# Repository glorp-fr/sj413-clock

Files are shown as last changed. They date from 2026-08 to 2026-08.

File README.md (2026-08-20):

# Module Horloge / Inclinomètre — Suzuki Samurai SJ413

Remplacement de l'horloge d'origine du tableau de bord d'un Suzuki Samurai
SJ413 (2001) par un module numérique : heure, inclinomètre tangage / roulis
avec silhouettes du véhicule, température extérieure. Basé sur une carte
LilyGO T-Display-S3 (ESP32-S3 + écran IPS 1.9" 170x320), dans un boîtier
imprimé en 3D aux dimensions de la découpe d'origine (63 x 42 mm),
assemblage par clips sans vis.



## Sommaire

- [Fonctionnalités](#fonctionnalités)
- [Matériel](#matériel)
- [Liste des composants (BOM)](#liste-des-composants-bom)
- [Structure du dépôt](#structure-du-dépôt)
- [Câblage](#câblage)
- [Firmware](#firmware)
- [Les écrans](#les-écrans)
- [Impression 3D](#impression-3d)
- [Assemblage](#assemblage)
- [Réglages / dépannage](#réglages--dépannage)
- [Évolutions envisagées](#évolutions-envisagées)
- [Historique des révisions](#historique-des-révisions)

## Fonctionnalités

- **Inclinomètre** : écran coupé en deux verticalement — tangage à gauche
  (Samurai vu de profil, roue de secours à l'arrière), roulis à droite
  (vue arrière, roue de secours sur la porte, pneus sous la carrosserie).
  Les silhouettes pivotent par rapport à un horizon fixe.
- **Alerte à deux niveaux par axe** : ambre à l'approche du seuil, rouge
  avec cadre clignotant en critique. Chaque moitié est indépendante.
- **Horloge** temps réel, conserve l'heure véhicule débranché.
- **Température extérieure** par sonde étanche déportée.
- Navigation à 2 boutons — **ceux déjà intégrés à la carte**, aucun bouton
  supplémentaire à câbler.
- Port USB-C accessible depuis l'extérieur du boîtier.
- Mode simulation intégré : tout le firmware tourne sans aucun capteur.

## Matériel

La carte est une **LilyGO T-Display-S3**. Deux points la caractérisent et
conditionnent tout le reste du projet :

**L'écran utilise un bus parallèle 8 bits, pas du SPI.** C'est contre-intuitif
et beaucoup de tutoriels se trompent. Il ne faut donc pas configurer
`User_Setup.h` à la main avec des broches SPI : un fichier de configuration
tout prêt existe (voir [Firmware](#firmware)).

**Ce bus consomme énormément de broches** : seules 13 GPIO sont sorties sur
le connecteur, contre une vingtaine sur la plupart des cartes ESP32-S3. Le
projet en utilise 5, il reste donc de la marge, mais ça se planifie.

La carte produit elle-même son 3,3 V : on lui fournit du 5 V sur sa broche
dédiée, et elle alimente tous les capteurs en 3,3 V depuis sa broche 3V3.
**Aucun capteur n'est alimenté en 5 V** — les GPIO de l'ESP32-S3 ne sont pas
tolérants au 5 V, et cette règle élimine tout risque d'en envoyer sur une
entrée par accident.

## Liste des composants (BOM)

| Composant | Spécifications | Qté | Rôle |
| :--- | :--- | :---: | :--- |
| Carte microcontrôleur | LilyGO T-Display-S3 (ESP32-S3, écran IPS 1.9" 170x320, ST7789 parallèle 8 bits) | 1 | Cerveau + affichage + boutons |
| Capteur d'inclinaison | MPU-6050 (6 axes, I2C) | 1 | Tangage / roulis |
| Horloge temps réel | Module RTC DS3231 + pile CR2032 | 1 | Garde l'heure hors tension |
| Sonde de température | DS18B20 étanche, câble 1,5–2 m (1-Wire) | 1 | Température extérieure |
| Résistance | 4,7 kΩ | 1 | Tirage de la ligne 1-Wire |
| Alimentation | Convertisseur DC-DC step-down 12V → 5V, 3A | 1 | Adapte le 12V véhicule |
| Protection | Diode 1N4007 + porte-fusible 1A | 1 lot | Protège du réseau 12V |
| Câblage | Fil souple 24 AWG, gaine thermo, câble Qwiic/JST | 1 lot | Connexions |
| Impression 3D | Filament PETG ou ASA noir mat | ~60 g | Façade + boîtier |

Coût estimé (hors imprimante) : **35–50 €**.

Les micro-boutons silicone 8x8 mm figuraient dans les versions précédentes :
ils ne sont plus nécessaires, les deux boutons de la carte (BOOT et KEY)
tombent exactement sur les broches prévues. La façade conserve toutefois
leurs emplacements dans le fichier CAO, à percer ou non selon le choix
d'implantation finale.

## Structure du dépôt

```
.
├── README.md
├── wiring.jpg
├── firmware/
│   ├── samurai_dashboard/          # firmware principal
│   │   └── samurai_dashboard.ino
│   ├── 00_test_hello_world/        # validation matérielle
│   │   └── 00_test_hello_world.ino
│   └── 01_ecran_inclinometre/      # écran inclinomètre seul
│       └── 01_ecran_inclinometre.ino
└── cad/
    ├── 01_facade_samurai.scad
    └── 02_boitier_corps.scad
```

Chaque croquis est dans un dossier à son nom : c'est ce qu'exige l'IDE
Arduino.

Les deux fichiers `.scad` partagent le même repère de coordonnées et les
mêmes variables (`largeur_trou`, `largeur_patte`, `x_patte_trou`) — une
dimension modifiée doit être reportée dans les deux.

## Câblage

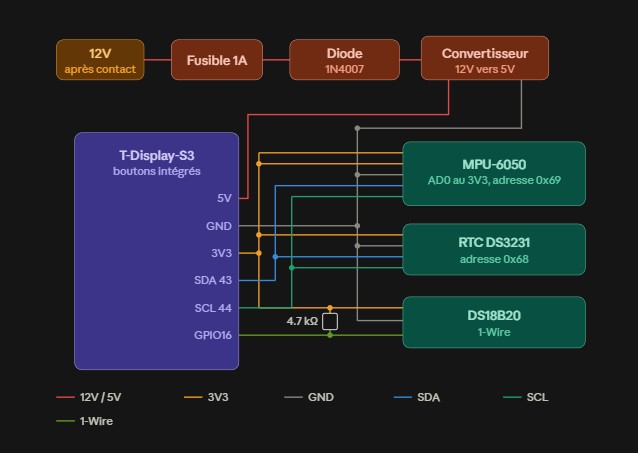
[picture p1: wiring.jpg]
wiring


Convention de lecture : un point noir = connexion réelle ; un croisement de
fils sans point = pas de contact.

### Affectation des broches

| Signal | GPIO | Remarque |
| :--- | :--- | :--- |
| I2C SDA / SCL | 43 / 44 | Connecteur Qwiic / STEMMA QT |
| DS18B20 | 16 | 1-Wire |
| Boutons | 0 (BOOT) / 14 (KEY) | Déjà intégrés à la carte |
| Alimentation périphériques | 15 | **Réservé** — doit rester HIGH |
| Rétroéclairage | 38 | **Réservé** |

Le **connecteur Qwiic** de la carte sort déjà 3V3, GND, SDA et SCL sur une
prise JST 4 points : les capteurs I2C s'y chaînent avec des câbles tout
faits, sans soudure. Dans un boîtier encastré qui vibre, c'est nettement
plus fiable que des fils volants.

Les sources documentaires se contredisent sur les broches I2C par défaut
(43/44 ou 18/17 selon les pages). Vérifiez le marquage de votre carte ;
de toute façon `Wire.begin(SDA, SCL)` permet de les imposer.

### Conflit d'adresses I2C — à ne pas rater

Le MPU-6050 et le DS3231 occupent **tous deux l'adresse 0x68** par défaut.
Il faut relier la broche **AD0 du MPU-6050 au 3V3** pour le basculer en
**0x69**, ce que le firmware attend (`ADRESSE_MPU`). Sans ce cavalier, les
deux capteurs se marchent dessus et aucun ne répond correctement.

### Autres points

- **Masse commune obligatoire** entre convertisseur, carte et capteurs.
  C'est le fil le plus souvent oublié, et la première cause de bus I2C muet.
- **DS18B20** : résistance de 4,7 kΩ entre la ligne de données et le 3V3,
  sauf si votre module l'intègre déjà. Le câble étant long, placez-la côté
  carte, pas côté sonde.
- **Sens de la diode** : bague côté convertisseur, sinon rien ne s'allume.
- **Alimentez sur le +12V après contact**, pas sur le permanent, sinon le
  module tourne en continu et vide la batterie en quelques jours. Le DS3231
  garde l'heure grâce à sa pile.

## Firmware

### Configuration préalable de TFT_eSPI (une seule fois)

Dans le dossier de la bibliothèque `TFT_eSPI`, ouvrir `User_Setup_Select.h`,
commenter la ligne active et décommenter :

```cpp
#include <User_Setups/Setup206_LilyGo_T_Display_S3.h>
```

Ne modifiez pas `User_Setup.h` à la main : cette carte est en parallèle
8 bits, un brochage SPI trouvé sur un blog ne fonctionnera pas. Ce fichier
est **écrasé à chaque mise à jour de la bibliothèque** — si l'écran redevient
noir sans raison, c'est presque toujours ça.

### Réglages Arduino IDE

| Option | Valeur |
| :--- | :--- |
| Carte | ESP32S3 Dev Module |
| USB CDC On Boot | Enabled |
| Flash Size | 16MB (128Mb) |
| Partition Scheme | 16M Flash (3M APP/9.9MB FATFS) |
| PSRAM | **OPI PSRAM** |
| USB Mode | CDC and JTAG |

LilyGO signale que `TFT_eSPI` ne fonctionne pas correctement avec les
versions du paquet **esp32 supérieures à 2.0.14**. Écran noir alors que tout
le reste semble bon : redescendez en 2.0.14.

### Bibliothèques

`TFT_eSPI` (Bodmer), `Adafruit MPU6050` + `Adafruit Unified Sensor`,
`RTClib` (Adafruit), `OneWire` + `DallasTemperature` (Miles Burton).

### Mode simulation

En tête de `samurai_dashboard.ino` :

```cpp
#define SIMULATION 1
```

À `1`, tout tourne **sans aucun capteur branché** : angles sinusoïdaux
balayant les trois niveaux d'alerte, heure interne, température factice.
À `0`, les capteurs réels sont utilisés. Les deux chemins de compilation
sont indépendants — en simulation, aucune bibliothèque de capteur n'est
même incluse.

### Ordre de mise en route conseillé

1. `00_test_hello_world` — valide écran, boutons et liaison série. Rien de
   branché, juste l'USB-C.
2. `01_ecran_inclinometre` — l'écran inclinomètre seul, en simulation.
3. `samurai_dashboard` en `SIMULATION 1` — l'ensemble des modes.
4. Câbler les capteurs, passer en `SIMULATION 0`.

### Premier réglage de l'heure

Décommenter **une seule fois** la ligne `rtc.adjust(...)` dans `setup()`,
téléverser, puis la recommenter et téléverser à nouveau — sinon l'heure
repart à la date de compilation à chaque redémarrage.

### Commandes

| Action | Effet |
| :--- | :--- |
| KEY, appui court | Mode suivant (inclinomètre → horloge → veille) |
| BOOT, appui long | Calibrage du zéro de l'inclinomètre |

Le calibrage se fait **véhicule à plat, moteur arrêté** : il moyenne 16
lectures et mémorise l'écart comme nouvelle référence.

## Les écrans

### Inclinomètre

L'écran est coupé en deux verticalement. À gauche le tangage avec le Samurai
vu de profil ; à droite le roulis avec la vue arrière. Une ligne d'horizon
en pointillés reste fixe : c'est le véhicule qui bascule par rapport à elle,
comme sur un horizon artificiel.

Les silhouettes sont tracées en trigonométrie, pas en bitmap : elles
pivotent réellement, sans stocker d'images.

**Saturation graphique :** la silhouette de profil est longue, donc au-delà
de ~34° ses extrémités viendraient chevaucher le titre et la valeur. Le
dessin est donc saturé à cette limite, **mais la valeur numérique affichée
reste toujours l'angle réel**. C'est le comportement des vrais indicateurs :
le graphique bute, le chiffre continue.

### Seuils d'alerte

| Niveau | Silhouette | Titre + valeur | Cadre |
| :--- | :--- | :--- | :--- |
| Normal | vert | blanc | — |
| Approche | ambre | ambre | — |
| Critique | rouge | rouge | rouge clignotant |

Valeurs par défaut : roulis 22° / 30°, tangage 27° / 35°. Le roulis est plus
bas car sur un Samurai (empattement court, voie étroite, centre de gravité
haut) c'est le basculement latéral le vrai danger ; en montée on perd
l'adhérence ou on recule bien avant de basculer.

> **Ces valeurs sont un point de départ volontairement conservateur, pas
> une limite constructeur.** L'angle réel de bascule dépend des pneus, d'un
> éventuel rehaussement, du chargement et surtout d'une galerie de toit — un
> Samurai réhaussé et chargé sur le toit part nettement plus tôt. Et un angle
> qui se tient à l'arrêt ne se tient pas en dynamique : une bosse, un
> freinage, un passager qui se déplace suffisent. Cet écran est une aide à la
> lecture du terrain, **jamais une autorisation d'aller jusqu'au seuil**. Si
> vous ajustez ces constantes, faites-le vers le bas.

### Horloge

Heure en grands chiffres, secondes, date et température extérieure. Dessinée
directement sur l'écran sans sprite : le contenu ne change qu'une fois par
seconde, et cela économise les 108 Ko qu'occuperait un sprite plein écran.

## Impression 3D

- Matière : **PETG ou ASA** noir mat. Le PLA se déforme l'été derrière un
  pare-brise (>60 °C dans l'habitacle).
- Hauteur de couche 0,16–0,20 mm, remplissage 20–30 %.
- Façade : face visible contre le plateau, sans support.
- Boîtier : à plat, ouverture vers le haut ; supports légers sous la découpe
  USB-C selon le trancheur.

Les deux fichiers ont été rendus avec OpenSCAD et vérifiés en maillage
2-manifold valide. L'alignement pattes / encoches a été contrôlé
numériquement sur les trois axes.

## Assemblage

1. Relier AD0 du MPU-6050 au 3V3 (adresse 0x69), puis chaîner MPU-6050 et
   DS3231 sur le connecteur Qwiic.
2. Câbler la sonde DS18B20 sur GPIO16 avec sa résistance de tirage.
3. Glisser l'électronique dans le boîtier par l'avant : le PCB bute contre
   l'étagère interne (5 mm), juste derrière la fenêtre de l'écran.
4. Passer le câble 12V/GND par l'ouverture arrière, brancher le
   convertisseur avec diode et fusible en amont.
5. Clipser la façade : les deux pattes s'enfoncent par friction dans les
   encoches. Appuyer fermement et de façon répartie sur toute la largeur,
   pas sur un coin.
6. Insérer dans la découpe du tableau de bord — le débord de 2,5 mm masque
   les bords et les fentes des encoches.
7. Téléverser, régler l'heure du RTC, calibrer le zéro véhicule à plat.

## Réglages / dépannage

| Symptôme | Cause probable |
| :--- | :--- |
| Écran noir | `Setup206` non sélectionné dans `User_Setup_Select.h`, ou paquet esp32 > 2.0.14 |
| Écran noir hors USB | GPIO15 non mis à HIGH |
| Téléversement impossible | Maintenir BOOT, appuyer sur RST, relâcher RST puis BOOT |
| Capteurs I2C muets | AD0 du MPU non relié au 3V3 (conflit 0x68), ou masse non commune |
| Température à `--` | Sonde absente ou résistance de tirage manquante |
| Heure fausse au démarrage | Pile CR2032 vide, ou `rtc.adjust(...)` jamais exécuté |
| Silhouette penchée à l'envers | Inverser `SENS_TANGAGE` ou `SENS_ROULIS` (1 ↔ -1) |
| Clip trop lâche ou trop dur | Ajuster `epaisseur_patte` par pas de 0,1 mm, réimprimer la façade seule |

## Évolutions envisagées

**Boussole.** Le MPU-6050 est un 6 axes, il n'a pas de magnétomètre : il
faut un module supplémentaire (QMC5883L « GY-271 », ~2 €, adresse 0x0D). La
difficulté n'est pas le module mais l'environnement : encastré dans un
tableau de bord en acier, à côté de l'écran et du WiFi, il exige une
calibration hard-iron/soft-iron **faite dans le véhicule, module en place**,
à refaire si quoi que ce soit bouge. Il faut aussi le compenser en
inclinaison — l'accéléromètre du MPU-6050 est déjà là pour ça.

**GPS.** Un ATGM336H (~5 €) ou un NEO-M8N (~12 €) sur UART donne le cap réel
et la vitesse. Le cap GPS n'existe qu'**en mouvement** (au-delà de ~5 km/h),
le magnétomètre est le plus perturbé en roulant : les deux se complètent,
avec un basculement automatique selon la vitesse. Prévoir impérativement un
module à connecteur **IPEX** et une **antenne active déportée** — dans une
cage métallique, une antenne céramique intégrée n'accrochera jamais.

Le GPS pourrait remplacer le DS3231, mais mieux vaut garder le RTC :
l'accrochage prend de 30 s à plusieurs minutes, et jamais en parking
souterrain. Le RTC donne l'heure immédiatement, le GPS le resynchronise.

**Voltmètre batterie**, par pont diviseur sur une entrée ADC.

## Historique des révisions

- **v3** — Correction de deux erreurs importantes des versions précédentes :
  l'écran est en **parallèle 8 bits et non en SPI** (avec le fichier
  `Setup206` à sélectionner, au lieu d'une configuration manuelle vouée à
  l'échec), et le **conflit d'adresse I2C 0x68** entre MPU-6050 et DS3231
  (AD0 au 3V3 → 0x69). Ajout de l'écran inclinomètre avec silhouettes de
  Samurai, alertes à deux niveaux par axe, mode simulation complet, tableau
  d'affectation des broches, suppression des boutons externes au profit de
  ceux de la carte, clarification de l'alimentation en 3,3 V.
- **v2** — Correction d'un maillage STL non-manifold sur la façade,
  correction des 4 premiers mm du boîtier pleins par erreur, réalignement
  vérifié des clips, clip par crochet remplacé par un clip par interférence,
  ré-ajout du RTC et de la sonde de température au BOM, anti-rebond du
  firmware rendu non bloquant.
- **v1** — Version initiale.

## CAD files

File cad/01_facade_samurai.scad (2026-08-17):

// ============================================================
// MODULE HORLOGE / INCLINOMÈTRE SUZUKI SAMURAI SJ413
// Pièce 1/2 : FAÇADE AVANT — 01_facade_samurai.scad
// Carte : ESP32-S3 avec écran IPS 1.9" intégré (170x320, ST7789)
// Assemblage : pattes rectangulaires en interférence (pas de vis)
// ============================================================
// IMPORTANT — repère PARTAGÉ avec 02_boitier_corps.scad :
// (0,0) = coin bas-gauche de la DÉCOUPE DU TABLEAU DE BORD
// (63x42mm), PAS le coin de la façade elle-même. La façade
// déborde donc de -rebord_facade à largeur_trou+rebord_facade.
// Toute position de patte/bouton/écran ci-dessous est exprimée
// en coordonnées "trou", puis translatée de +rebord_facade pour
// entrer dans le repère local du panneau. Cela permet de copier
// telles quelles les mêmes coordonnées "trou" dans le fichier du
// boîtier sans recalcul.
// ============================================================

$fn = 40;

// --- Dimensions de la découpe d'origine du tableau de bord ---
largeur_trou  = 63.0;
hauteur_trou  = 42.0;
rebord_facade = 2.5;               // débord de la collerette autour du trou

L_facade = largeur_trou + (rebord_facade * 2); // 68 mm
H_facade = hauteur_trou + (rebord_facade * 2); // 47 mm
epaisseur_facade = 3.0;

// --- Zone d'affichage utile de l'écran 1.9" (coord. "trou") ---
largeur_ecran     = 42.5;
hauteur_ecran     = 23.0;
x_ecran_trou      = 3.5;                              // marge à gauche
y_ecran_trou      = (hauteur_trou - hauteur_ecran)/2;  // centré verticalement

// --- Boutons poussoirs silicone 8x8x5mm (jeu de perçage 0.2mm) ---
largeur_bouton = 8.2;
hauteur_bouton = 8.2;
x_bouton_trou      = 50.0;
y_bouton_haut_trou = 9.5;
y_bouton_bas_trou  = 24.3;

// --- Pattes d'assemblage en interférence (clips sans vis) ---
// Cohérent avec 02_boitier_corps.scad :
largeur_patte   = 15.0;
epaisseur_patte = 1.9;   // légèrement > l'ouverture de l'encoche -> interférence
longueur_patte  = 4.0;   // reste dans la zone d'étagère avant du boîtier (voir profondeur_ledge)
x_patte_trou    = (largeur_trou - largeur_patte) / 2;   // centré en largeur : 24.0

module rectangle_arrondi(l, h, r) {
    hull() {
        translate([r, r]) circle(r=r);
        translate([l-r, r]) circle(r=r);
        translate([l-r, h-r]) circle(r=r);
        translate([r, h-r]) circle(r=r);
    }
}

// Patte simple avec léger chanfrein d'entrée (reste manifold via hull)
module patte_interference(largeur, epaisseur, longueur) {
    hull() {
        cube([largeur, epaisseur, 0.1]);                    // base, collée à la façade
        translate([0.6, 0, longueur])
            cube([largeur - 1.2, epaisseur, 0.1]);            // bout chanfreiné, guide l'insertion
    }
}

module facade_1_9() {
    difference() {
        union() {
            // Cadre principal de façade
            linear_extrude(height = epaisseur_facade)
                rectangle_arrondi(L_facade, H_facade, 3.0);

            // Patte haute (s'enfonce dans l'encoche haute du boîtier)
            translate([rebord_facade + x_patte_trou, rebord_facade - epaisseur_patte + 0.4, epaisseur_facade])
                patte_interference(largeur_patte, epaisseur_patte, longueur_patte);

            // Patte basse (s'enfonce dans l'encoche basse du boîtier)
            translate([rebord_facade + x_patte_trou, rebord_facade + hauteur_trou - 0.4, epaisseur_facade])
                patte_interference(largeur_patte, epaisseur_patte, longueur_patte);
        }

        // Fenêtre centrale pour l'écran
        translate([rebord_facade + x_ecran_trou, rebord_facade + y_ecran_trou, -1])
            linear_extrude(height = epaisseur_facade + 6)
                rectangle_arrondi(largeur_ecran, hauteur_ecran, 1.5);

        // Bouton 1 (haut) : cycle des modes d'affichage
        translate([rebord_facade + x_bouton_trou, rebord_facade + y_bouton_haut_trou, -1])
            linear_extrude(height = epaisseur_facade + 6)
                rectangle_arrondi(largeur_bouton, hauteur_bouton, 1.0);

        // Bouton 2 (bas) : calibrage / réglage
        translate([rebord_facade + x_bouton_trou, rebord_facade + y_bouton_bas_trou, -1])
            linear_extrude(height = epaisseur_facade + 6)
                rectangle_arrondi(largeur_bouton, hauteur_bouton, 1.0);
    }
}

facade_1_9();

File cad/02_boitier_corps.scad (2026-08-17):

// ============================================================
// MODULE HORLOGE / INCLINOMÈTRE SUZUKI SAMURAI SJ413
// Pièce 2/2 : CORPS DU BOÎTIER ARRIÈRE — 02_boitier_corps.scad
// Carte : ESP32-S3 avec écran IPS 1.9" intégré (170x320, ST7789)
// ============================================================
// IMPORTANT — repère PARTAGÉ avec 01_facade_samurai.scad :
// (0,0) = coin bas-gauche de la DÉCOUPE DU TABLEAU DE BORD.
// Ce fichier est construit directement dans ce repère (pas de
// débord à soustraire). Les positions des encoches ci-dessous
// utilisent les MÊMES variables "x_patte_trou / largeur_patte /
// longueur_patte" que la façade — gardez-les synchronisées si
// vous modifiez l'une ou l'autre pièce.
// ============================================================

$fn = 40;

// --- Dimensions (doivent rester identiques à celles de la façade) ---
largeur_trou       = 63.0;
hauteur_trou       = 42.0;
profondeur_boitier = 45.0;
epaisseur_paroi    = 2.4;

// --- Étagère interne (ledge) qui retient le PCB contre la vitre ---
// Sur les premiers "profondeur_ledge" mm, l'ouverture est réduite de
// epaisseur_ledge en plus de l'épaisseur de paroi normale : le PCB,
// glissé depuis l'avant, bute sur ce rebord et s'arrête net derrière
// la fenêtre de l'écran.
profondeur_ledge = 5.0;
epaisseur_ledge  = 2.0;

// --- Port USB-C (accès arrière, pour prog./alimentation directe) ---
largeur_usb = 12.0;
hauteur_usb = 7.0;

// --- Encoches d'assemblage (DOIVENT matcher la façade) ---
largeur_patte   = 15.0;
epaisseur_patte = 1.9;
longueur_patte  = 4.0;                              // reste dans la zone d'étagère (< profondeur_ledge)
x_patte_trou    = (largeur_trou - largeur_patte)/2;  // 24.0 — centré, identique à la façade
jeu_largeur     = 0.4;                               // jeu latéral autour de la patte

module rectangle_arrondi(l, h, r) {
    hull() {
        translate([r, r]) circle(r=r);
        translate([l-r, r]) circle(r=r);
        translate([l-r, h-r]) circle(r=r);
        translate([r, h-r]) circle(r=r);
    }
}

module boitier_corps() {
    difference() {
        // Corps principal qui s'enfonce dans le tableau de bord
        linear_extrude(height = profondeur_boitier)
            rectangle_arrondi(largeur_trou, hauteur_trou, 3.0);

        // --- Cavité principale (profonde), paroi standard ---
        translate([epaisseur_paroi, epaisseur_paroi, profondeur_ledge])
            linear_extrude(height = profondeur_boitier - profondeur_ledge + 1)
                rectangle_arrondi(
                    largeur_trou - 2*epaisseur_paroi,
                    hauteur_trou - 2*epaisseur_paroi, 1.5);

        // --- Cavité avant (étagère), ouverture réduite pour retenir le PCB ---
        translate([epaisseur_paroi + epaisseur_ledge, epaisseur_paroi + epaisseur_ledge, -1])
            linear_extrude(height = profondeur_ledge + 1)
                rectangle_arrondi(
                    largeur_trou - 2*(epaisseur_paroi + epaisseur_ledge),
                    hauteur_trou - 2*(epaisseur_paroi + epaisseur_ledge), 1.0);

        // Accès port USB-C au dos (centré, aligné sur le connecteur de la carte)
        translate([largeur_trou/2 - largeur_usb/2, 8.0, profondeur_boitier - 5.0])
            cube([largeur_usb, hauteur_usb, 10.0]);

        // Passage des câbles d'alimentation 12V / GND (régulateur -> faisceau)
        translate([largeur_trou/2 - 8.0, hauteur_trou - 14.0, profondeur_boitier - 5.0])
            cube([16.0, 8.0, 10.0]);

        // --- Encoche haute (reçoit la patte haute de la façade) ---
        // Traverse toute l'épaisseur de la paroi (haut) pour un ajustement
        // par friction — la façade déborde du trou et masque cette fente.
        translate([x_patte_trou - jeu_largeur/2, -2, -0.5])
            cube([largeur_patte + jeu_largeur, 3.0, longueur_patte + 1]);

        // --- Encoche basse (reçoit la patte basse de la façade) ---
        translate([x_patte_trou - jeu_largeur/2, hauteur_trou - 1.0, -0.5])
            cube([largeur_patte + jeu_largeur, 3.0, longueur_patte + 1]);

        // --- Fentes de refroidissement pour l'ESP32-S3 ---
        // En dehors de la zone centrale des encoches (x 22 à 41) et de
        // la zone d'étagère avant : positionnées sur les côtés, plus
        // profondes dans le boîtier (z > 12).
        for (i = [0:2]) {
            translate([4 + i*4, hauteur_trou - epaisseur_paroi - 1, 12])
                cube([2.2, epaisseur_paroi + 2, 25]);
            translate([largeur_trou - 16 + i*4, hauteur_trou - epaisseur_paroi - 1, 12])
                cube([2.2, epaisseur_paroi + 2, 25]);
            translate([4 + i*4, -1, 12])
                cube([2.2, epaisseur_paroi + 2, 25]);
            translate([largeur_trou - 16 + i*4, -1, 12])
                cube([2.2, epaisseur_paroi + 2, 25]);
        }
    }
}

boitier_corps();

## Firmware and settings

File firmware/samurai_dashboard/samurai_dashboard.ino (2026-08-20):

/* ============================================================
 * MODULE HORLOGE / INCLINOMÈTRE — SUZUKI SAMURAI SJ413
 * Carte : LilyGO T-Display-S3 (ESP32-S3 + ST7789 170x320,
 *         bus PARALLÈLE 8 bits — surtout pas du SPI)
 * ------------------------------------------------------------
 * Modes (bouton KEY = mode suivant) :
 *   0. Inclinomètre — écran coupé en deux : tangage (profil) et
 *      roulis (vue arrière), silhouettes de Samurai qui pivotent
 *   1. Horloge      — heure, date, température extérieure
 *   2. Veille       — écran noir
 *
 * Bouton BOOT, appui long : calibrage du zéro de l'inclinomètre
 * (à faire véhicule à plat, moteur arrêté).
 * ------------------------------------------------------------
 * MODE SIMULATION
 * Mettre SIMULATION à 1 pour faire tourner l'ensemble SANS aucun
 * capteur branché (angles sinusoïdaux, heure interne, température
 * factice). Mettre 0 quand les capteurs sont câblés.
 * ------------------------------------------------------------
 * PRÉREQUIS TFT_eSPI (une seule fois) :
 *   Dans User_Setup_Select.h : commenter #include <User_Setup.h>
 *   et décommenter
 *   #include <User_Setups/Setup206_LilyGo_T_Display_S3.h>
 *
 * ARDUINO IDE : ESP32S3 Dev Module / PSRAM OPI / Flash 16MB /
 *   Partition 16M Flash (3M APP/9.9MB FATFS) / USB CDC On Boot
 * ============================================================ */

#define SIMULATION 1

#include <Arduino.h>
#include <TFT_eSPI.h>

#if !SIMULATION
  #include <Wire.h>
  #include <Adafruit_MPU6050.h>
  #include <Adafruit_Sensor.h>
  #include <RTClib.h>
  #include <OneWire.h>
  #include <DallasTemperature.h>
#endif

/* ---------------- Broches ---------------- */
#define PIN_POWER_ON   15    // alimentation des périphériques : DOIT être HIGH
#define PIN_BTN_BOOT    0    // bouton intégré gauche
#define PIN_BTN_KEY    14    // bouton intégré droit
#define PIN_ONEWIRE    16    // sonde DS18B20
#define PIN_I2C_SDA    43    // connecteur Qwiic / STEMMA QT
#define PIN_I2C_SCL    44

/* MPU-6050 forcé en 0x69 (broche AD0 reliée au 3V3) : en 0x68 par
 * défaut il entrerait en conflit avec le DS3231, qui occupe la même
 * adresse. Sans ce cavalier, les deux capteurs se marchent dessus. */
#define ADRESSE_MPU  0x69

/* ---------------- Géométrie de l'affichage ---------------- */
#define LARGEUR_ECRAN    320
#define HAUTEUR_ECRAN    170
#define LARGEUR_PANNEAU  (LARGEUR_ECRAN / 2)

const float   ECHELLE     = 0.48f;   // valeurs validées : aux angles extrêmes
const int16_t CY_VEHICULE = 72;      // la silhouette ne mord ni sur le titre
const int16_t Y_HORIZON   = 84;      // ni sur la valeur

/* La silhouette de profil est longue : au-delà de ~34° ses extrémités
 * viendraient chevaucher le texte. On sature l'inclinaison DESSINÉE ;
 * la valeur numérique affichée reste toujours l'angle réel. */
const float ANGLE_DESSIN_MAX = 34.0f;

/* ---------------- Seuils d'alerte ----------------
 * Deux niveaux par axe. Le roulis est plus bas que le tangage : sur un
 * Samurai (empattement court, voie étroite, centre de gravité haut)
 * c'est le basculement latéral le vrai danger — en montée on perd
 * l'adhérence ou on recule bien avant de basculer.
 *
 * ATTENTION : point de départ VOLONTAIREMENT CONSERVATEUR, pas une
 * limite constructeur. L'angle réel de bascule dépend des pneus, d'un
 * rehaussement, du chargement et surtout d'une galerie de toit. Un
 * angle tenu à l'arrêt ne se tient pas en dynamique : une bosse, un
 * freinage, un passager qui se déplace suffisent. Cet écran est une
 * aide à la lecture du terrain, jamais une autorisation d'aller
 * jusqu'au seuil. Ajustez ces valeurs vers le BAS, pas vers le haut. */
const float TANGAGE_ATTENTION = 27.0f;
const float TANGAGE_CRITIQUE  = 35.0f;
const float ROULIS_ATTENTION  = 22.0f;
const float ROULIS_CRITIQUE   = 30.0f;

/* Sens de rotation : si une silhouette penche à l'envers une fois
 * installée dans le véhicule, inverser le 1 en -1 ici. */
#define SENS_TANGAGE   1
#define SENS_ROULIS   -1

TFT_eSPI tft = TFT_eSPI();
TFT_eSprite panneau = TFT_eSprite(&tft);   // un seul sprite, réutilisé pour les 2 moitiés

#if !SIMULATION
  Adafruit_MPU6050 mpu;
  RTC_DS3231 rtc;
  OneWire oneWire(PIN_ONEWIRE);
  DallasTemperature sondeExt(&oneWire);
  bool mpuOk = false, rtcOk = false;
#endif

uint16_t COUL_VEHICULE, COUL_ATTENTION, COUL_ALERTE, COUL_TITRE, COUL_VALEUR, COUL_HORIZON;

enum Mode { MODE_INCLINO, MODE_HORLOGE, MODE_VEILLE, NB_MODES };
uint8_t mode = MODE_INCLINO;
bool modeChange = true;

float offsetTangage = 0.0f, offsetRoulis = 0.0f;
float tempExterieure = NAN;

/* ---------------- Silhouettes (coordonnées du dessin, centrées) ---------------- */

const int8_t PROFIL_CAISSE[][2] = {
  {-92,6},{-92,-10},{-84,-10},{-84,-24},{-46,-26},{-36,-58},{54,-58},
  {58,-26},{58,6},{54,6},{54,-18},{14,-18},{14,6},{-36,6},{-36,-18},
  {-76,-18},{-76,6}
};
const uint8_t PROFIL_CAISSE_N = 17;
const int8_t PROFIL_SECOURS[][2] = { {58,-46},{71,-46},{71,-4},{58,-4} };
const int8_t PROFIL_VITRES[][2]  = { {-30,-54},{-30,-30},{48,-30},{48,-54} };

const int8_t ARRIERE_CAISSE[][2] = { {-50,4},{-50,-52},{50,-52},{50,4} };
const int8_t ARRIERE_VITRE[][2]  = { {-40,-46},{-40,-24},{40,-24},{40,-46} };
const int8_t ARRIERE_FEU[][2]    = { {-44,-18},{-32,-18},{-32,-3},{-44,-3} };
const int8_t ARRIERE_PNEU_G[][2] = { {-44,6},{-27,6},{-27,26},{-44,26} };
const int8_t ARRIERE_PNEU_D[][2] = { {27,6},{44,6},{44,26},{27,26} };

/* ---------------- Rotation et tracé ---------------- */

struct Repere { float cosA, sinA, cx, cy; };

Repere faireRepere(float angleDeg, float cx, float cy) {
  Repere r;
  if (angleDeg >  ANGLE_DESSIN_MAX) angleDeg =  ANGLE_DESSIN_MAX;
  if (angleDeg < -ANGLE_DESSIN_MAX) angleDeg = -ANGLE_DESSIN_MAX;
  float a = angleDeg * DEG_TO_RAD;
  r.cosA = cosf(a);
  r.sinA = sinf(a);
  r.cx = cx;
  r.cy = cy;
  return r;
}

void projeter(const Repere &r, float x, float y, int16_t &sx, int16_t &sy) {
  sx = (int16_t)lroundf(r.cx + (x * r.cosA - y * r.sinA) * ECHELLE);
  sy = (int16_t)lroundf(r.cy + (x * r.sinA + y * r.cosA) * ECHELLE);
}

void polyligne(const int8_t pts[][2], uint8_t n, bool fermee,
               const Repere &r, uint16_t couleur, bool epais) {
  int16_t xd, yd, xp, yp, xc, yc;
  projeter(r, pts[0][0], pts[0][1], xd, yd);
  xp = xd; yp = yd;
  for (uint8_t i = 1; i < n; i++) {
    projeter(r, pts[i][0], pts[i][1], xc, yc);
    panneau.drawLine(xp, yp, xc, yc, couleur);
    if (epais) panneau.drawLine(xp, yp + 1, xc, yc + 1, couleur);
    xp = xc; yp = yc;
  }
  if (fermee) {
    panneau.drawLine(xp, yp, xd, yd, couleur);
    if (epais) panneau.drawLine(xp, yp + 1, xd, yd + 1, couleur);
  }
}

void cerclePivote(const Repere &r, float x, float y, float rayon,
                  uint16_t couleur, bool epais) {
  int16_t sx, sy;
  projeter(r, x, y, sx, sy);
  int16_t rp = (int16_t)lroundf(rayon * ECHELLE);
  panneau.drawCircle(sx, sy, rp, couleur);
  if (epais && rp > 1) panneau.drawCircle(sx, sy, rp - 1, couleur);
}

/* ---------------- Niveaux d'alerte ---------------- */

uint8_t niveauAlerte(float angle, float attention, float critique) {
  float a = fabsf(angle);
  if (a >= critique)  return 2;
  if (a >= attention) return 1;
  return 0;
}

uint16_t couleurNiveau(uint8_t niveau, uint16_t couleurNormale) {
  if (niveau == 2) return COUL_ALERTE;
  if (niveau == 1) return COUL_ATTENTION;
  return couleurNormale;
}

/* ---------------- Écran inclinomètre ---------------- */

void dessinerFond(const char *titre, uint16_t couleurTitre, uint8_t niveau) {
  panneau.fillSprite(TFT_BLACK);

  // Cadre rouge clignotant en critique : c'est ce qu'on capte en vision
  // périphérique sans quitter la piste des yeux.
  if (niveau == 2 && ((millis() / 400) % 2 == 0)) {
    panneau.drawRect(0, 0, LARGEUR_PANNEAU, HAUTEUR_ECRAN, COUL_ALERTE);
    panneau.drawRect(1, 1, LARGEUR_PANNEAU - 2, HAUTEUR_ECRAN - 2, COUL_ALERTE);
    panneau.drawRect(2, 2, LARGEUR_PANNEAU - 4, HAUTEUR_ECRAN - 4, COUL_ALERTE);
  }

  panneau.setTextDatum(TC_DATUM);
  panneau.setTextColor(couleurTitre, TFT_BLACK);
  panneau.drawString(titre, LARGEUR_PANNEAU / 2, 6, 2);

  for (int16_t x = 14; x < LARGEUR_PANNEAU - 14; x += 8) {
    panneau.drawFastHLine(x, Y_HORIZON, 4, COUL_HORIZON);
  }
}

void dessinerValeur(float angle, uint16_t couleur) {
  char txt[8];
  snprintf(txt, sizeof(txt), "%d", (int)lroundf(angle));

  panneau.setTextDatum(TC_DATUM);
  panneau.setTextColor(couleur, TFT_BLACK);
  panneau.drawString(txt, LARGEUR_PANNEAU / 2 - 6, 112, 6);

  // Le symbole ° n'existe pas dans la police 6 : on le dessine
  int16_t largeur = panneau.textWidth(txt, 6);
  int16_t xd = LARGEUR_PANNEAU / 2 - 6 + largeur / 2 + 9;
  panneau.drawCircle(xd, 122, 5, couleur);
  panneau.drawCircle(xd, 122, 4, couleur);
}

void dessinerProfil(float tangage) {
  uint8_t niveau = niveauAlerte(tangage, TANGAGE_ATTENTION, TANGAGE_CRITIQUE);
  uint16_t couleur = couleurNiveau(niveau, COUL_VEHICULE);

  dessinerFond("Tangage", couleurNiveau(niveau, COUL_TITRE), niveau);
  Repere r = faireRepere(SENS_TANGAGE * tangage, LARGEUR_PANNEAU / 2.0f, CY_VEHICULE);

  polyligne(PROFIL_CAISSE, PROFIL_CAISSE_N, true, r, couleur, true);
  polyligne(PROFIL_SECOURS, 4, true, r, couleur, false);   // roue de secours par la tranche
  polyligne(PROFIL_VITRES, 4, false, r, couleur, false);

  int16_t x1, y1, x2, y2;
  projeter(r, 8, -54, x1, y1);
  projeter(r, 8, -30, x2, y2);
  panneau.drawLine(x1, y1, x2, y2, couleur);               // montant central

  cerclePivote(r, -56, 4, 19, couleur, true);
  cerclePivote(r,  34, 4, 19, couleur, true);
  cerclePivote(r, -56, 4, 7, couleur, false);
  cerclePivote(r,  34, 4, 7, couleur, false);

  dessinerValeur(tangage, couleurNiveau(niveau, COUL_VALEUR));
  panneau.pushSprite(0, 0);
}

void dessinerArriere(float roulis) {
  uint8_t niveau = niveauAlerte(roulis, ROULIS_ATTENTION, ROULIS_CRITIQUE);
  uint16_t couleur = couleurNiveau(niveau, COUL_VEHICULE);

  dessinerFond("Roulis", couleurNiveau(niveau, COUL_TITRE), niveau);
  Repere r = faireRepere(SENS_ROULIS * roulis, LARGEUR_PANNEAU / 2.0f, CY_VEHICULE);

  polyligne(ARRIERE_CAISSE, 4, true, r, couleur, true);
  polyligne(ARRIERE_VITRE, 4, true, r, couleur, false);
  polyligne(ARRIERE_FEU, 4, true, r, couleur, false);

  int16_t x1, y1, x2, y2;
  projeter(r, -50, 6, x1, y1);
  projeter(r,  50, 6, x2, y2);
  panneau.drawLine(x1, y1, x2, y2, couleur);               // pare-chocs
  panneau.drawLine(x1, y1 + 1, x2, y2 + 1, couleur);

  // Roue de secours : remplie en noir AVANT le contour, pour masquer le
  // tracé de la vitre qu'elle recouvre.
  int16_t xs, ys;
  projeter(r, 14, -20, xs, ys);
  int16_t rs = (int16_t)lroundf(18 * ECHELLE);
  panneau.fillCircle(xs, ys, rs, TFT_BLACK);
  panneau.drawCircle(xs, ys, rs, couleur);
  panneau.drawCircle(xs, ys, rs - 1, couleur);
  panneau.drawCircle(xs, ys, (int16_t)lroundf(7 * ECHELLE), couleur);

  polyligne(ARRIERE_PNEU_G, 4, true, r, couleur, true);    // pneus vus de dos
  polyligne(ARRIERE_PNEU_D, 4, true, r, couleur, true);

  dessinerValeur(roulis, couleurNiveau(niveau, COUL_VALEUR));
  panneau.pushSprite(LARGEUR_PANNEAU, 0);
}

/* ---------------- Écran horloge ----------------
 * Dessiné directement sur l'écran (pas de sprite) : le contenu ne change
 * qu'une fois par seconde, le scintillement est invisible et on économise
 * les 108 Ko qu'occuperait un sprite plein écran. */

void dessinerHorloge(uint8_t h, uint8_t m, uint8_t s, uint16_t annee,
                     uint8_t mois, uint8_t jour, float tempC, bool complet) {
  if (complet) tft.fillScreen(TFT_BLACK);

  char heure[6], secondes[4], date[12], temp[16];
  snprintf(heure, sizeof(heure), "%02d:%02d", h, m);
  snprintf(secondes, sizeof(secondes), "%02d", s);
  snprintf(date, sizeof(date), "%02d/%02d/%04d", jour, mois, annee);
  if (isnan(tempC)) snprintf(temp, sizeof(temp), "Ext  --");
  else              snprintf(temp, sizeof(temp), "Ext  %.1fC", tempC);

  tft.setTextDatum(TL_DATUM);
  tft.setTextColor(COUL_VALEUR, TFT_BLACK);
  tft.drawString(heure, 18, 28, 7);

  tft.setTextColor(COUL_TITRE, TFT_BLACK);
  tft.drawString(secondes, 232, 62, 4);

  tft.setTextColor(COUL_VEHICULE, TFT_BLACK);
  tft.drawString(date, 18, 118, 4);
  tft.drawString(temp, 190, 118, 4);
}

/* ---------------- Lecture des capteurs ---------------- */

#if SIMULATION
float tempsSimule = 0.0f;
#endif

void lireAngles(float &tangage, float &roulis) {
#if SIMULATION
  tangage = 40.0f * sinf(tempsSimule * 0.6f);
  roulis  = 34.0f * sinf(tempsSimule * 0.41f + 1.2f);
#else
  if (!mpuOk) { tangage = 0; roulis = 0; return; }
  sensors_event_t a, g, t;
  mpu.getEvent(&a, &g, &t);
  tangage = atan2f(a.acceleration.x,
              sqrtf(a.acceleration.y * a.acceleration.y +
                    a.acceleration.z * a.acceleration.z)) * RAD_TO_DEG - offsetTangage;
  roulis  = atan2f(a.acceleration.y, a.acceleration.z) * RAD_TO_DEG - offsetRoulis;
#endif
}

void calibrerZero() {
#if !SIMULATION
  if (!mpuOk) return;
  // Moyenne sur quelques lectures : une seule mesure est bruitée.
  float st = 0, sr = 0;
  const uint8_t N = 16;
  for (uint8_t i = 0; i < N; i++) {
    sensors_event_t a, g, t;
    mpu.getEvent(&a, &g, &t);
    st += atan2f(a.acceleration.x,
            sqrtf(a.acceleration.y * a.acceleration.y +
                  a.acceleration.z * a.acceleration.z)) * RAD_TO_DEG;
    sr += atan2f(a.acceleration.y, a.acceleration.z) * RAD_TO_DEG;
    delay(10);
  }
  offsetTangage = st / N;
  offsetRoulis  = sr / N;
#endif
  tft.fillScreen(COUL_VEHICULE);
  delay(250);
  modeChange = true;
}

/* ---------------- Boutons (anti-rebond non bloquant) ---------------- */

struct Bouton {
  uint8_t pin;
  bool brut, stable;
  uint32_t front, debutAppui;
  bool longTraite;
};

Bouton btnKey  = { PIN_BTN_KEY,  HIGH, HIGH, 0, 0, false };
Bouton btnBoot = { PIN_BTN_BOOT, HIGH, HIGH, 0, 0, false };

// Retourne 0 = rien, 1 = appui court relâché, 2 = appui long atteint
uint8_t lireBouton(Bouton &b) {
  const uint16_t ANTIREBOND = 40, APPUI_LONG = 1500;
  uint8_t evt = 0;
  bool lu = digitalRead(b.pin);
  if (lu != b.brut) { b.front = millis(); b.brut = lu; }
  if ((millis() - b.front) > ANTIREBOND && lu != b.stable) {
    b.stable = lu;
    if (b.stable == LOW) { b.debutAppui = millis(); b.longTraite = false; }
    else if (!b.longTraite) evt = 1;
  }
  if (b.stable == LOW && !b.longTraite && (millis() - b.debutAppui) >= APPUI_LONG) {
    b.longTraite = true;
    evt = 2;
  }
  return evt;
}

/* ---------------- Setup / loop ---------------- */

uint32_t dernierRendu = 0, dernierTick = 0, dernierTemp = 0, derniereSeconde = 0;

void setup() {
  pinMode(PIN_POWER_ON, OUTPUT);
  digitalWrite(PIN_POWER_ON, HIGH);       // sans ça : écran noir hors USB

  Serial.begin(115200);
  pinMode(PIN_BTN_BOOT, INPUT_PULLUP);
  pinMode(PIN_BTN_KEY, INPUT_PULLUP);

  tft.init();
  tft.setRotation(1);
  tft.fillScreen(TFT_BLACK);

  COUL_VEHICULE  = tft.color565(93, 202, 165);
  COUL_ATTENTION = tft.color565(239, 159, 39);
  COUL_ALERTE    = tft.color565(226, 75, 74);
  COUL_TITRE     = tft.color565(180, 178, 169);
  COUL_VALEUR    = tft.color565(241, 239, 232);
  COUL_HORIZON   = tft.color565(68, 68, 65);

  panneau.setColorDepth(16);
  if (panneau.createSprite(LARGEUR_PANNEAU, HAUTEUR_ECRAN) == nullptr) {
    tft.setTextColor(COUL_ALERTE, TFT_BLACK);
    tft.drawString("Sprite: memoire insuffisante", 10, 10, 2);
    while (true) delay(1000);
  }

#if !SIMULATION
  Wire.begin(PIN_I2C_SDA, PIN_I2C_SCL);

  mpuOk = mpu.begin(ADRESSE_MPU);
  if (mpuOk) {
    mpu.setAccelerometerRange(MPU6050_RANGE_2_G);
    mpu.setGyroRange(MPU6050_RANGE_250_DEG);
    mpu.setFilterBandwidth(MPU6050_BANDWIDTH_21_HZ);
  } else {
    Serial.println("MPU-6050 absent (AD0 bien relie au 3V3 pour 0x69 ?)");
  }

  rtcOk = rtc.begin();
  if (!rtcOk) Serial.println("DS3231 absent");
  // Premier flash : décommenter UNE FOIS pour régler l'heure, puis
  // recommenter et reflasher, sinon l'heure repart à la compilation.
  // else if (rtc.lostPower()) rtc.adjust(DateTime(F(__DATE__), F(__TIME__)));

  sondeExt.begin();
  sondeExt.setWaitForConversion(false);   // lecture non bloquante
  sondeExt.requestTemperatures();
#endif

  Serial.println(SIMULATION ? "Demarrage en MODE SIMULATION" : "Demarrage en mode capteurs");
}

void loop() {
  uint32_t maintenant = millis();

  // KEY : mode suivant
  if (lireBouton(btnKey) == 1) {
    mode = (mode + 1) % NB_MODES;
    modeChange = true;
  }
  // BOOT appui long : calibrage du zéro (uniquement en mode inclinomètre)
  if (lireBouton(btnBoot) == 2 && mode == MODE_INCLINO) {
    calibrerZero();
  }

#if SIMULATION
  tempsSimule += (maintenant - dernierTick) / 1000.0f;
#endif
  dernierTick = maintenant;

  // Température extérieure : le DS18B20 met ~750 ms à convertir, on le
  // lit sans bloquer et on relance une conversion à chaque passage.
  if (maintenant - dernierTemp > 5000) {
    dernierTemp = maintenant;
#if SIMULATION
    tempExterieure = 17.0f + 3.0f * sinf(maintenant / 20000.0f);
#else
    float t = sondeExt.getTempCByIndex(0);
    tempExterieure = (t < -100) ? NAN : t;   // -127 = sonde absente
    sondeExt.requestTemperatures();
#endif
  }

  if (modeChange) {
    tft.fillScreen(TFT_BLACK);
    modeChange = false;
    derniereSeconde = 0;
  }

  if (mode == MODE_INCLINO) {
    if (maintenant - dernierRendu >= 40) {      // ~25 images/s
      dernierRendu = maintenant;
      float tangage, roulis;
      lireAngles(tangage, roulis);
      dessinerProfil(tangage);
      dessinerArriere(roulis);
      tft.drawFastVLine(LARGEUR_PANNEAU - 1, 12, HAUTEUR_ECRAN - 24, COUL_HORIZON);
    }
  } else if (mode == MODE_HORLOGE) {
    if (maintenant - derniereSeconde >= 1000) {
      derniereSeconde = maintenant;
#if SIMULATION
      uint32_t s = maintenant / 1000;
      dessinerHorloge((s / 3600) % 24, (s / 60) % 60, s % 60,
                      2026, 1, 1, tempExterieure, false);
#else
      if (rtcOk) {
        DateTime n = rtc.now();
        dessinerHorloge(n.hour(), n.minute(), n.second(),
                        n.year(), n.month(), n.day(), tempExterieure, false);
      } else {
        tft.setTextColor(COUL_ALERTE, TFT_BLACK);
        tft.drawString("RTC absent", 18, 60, 4);
      }
#endif
    }
  }
  // MODE_VEILLE : rien à dessiner, l'écran reste noir
}

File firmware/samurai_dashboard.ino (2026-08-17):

/* ============================================================
 * MODULE HORLOGE / INCLINOMÈTRE - SUZUKI SAMURAI SJ413
 * Carte : ESP32-S3 avec écran IPS 1.9" intégré (170x320, ST7789)
 * Capteurs : MPU-6050 (inclinaison), DS3231 (heure), DS18B20 (temp. ext.)
 * ------------------------------------------------------------
 * Bibliothèques requises (Gestionnaire de bibliothèques Arduino) :
 *   - TFT_eSPI (Bodmer)            -> écran
 *   - Adafruit MPU6050 + Adafruit Unified Sensor -> inclinomètre
 *   - RTClib (Adafruit)            -> horloge DS3231
 *   - OneWire + DallasTemperature (Miles Burton) -> sonde DS18B20
 *
 * IMPORTANT : TFT_eSPI doit être configuré (fichier User_Setup.h ou
 * User_Setup_Select.h) avec le pinout EXACT fourni par le fabricant
 * de votre carte ESP32-S3+écran (chaque revendeur câble différemment
 * le bus SPI de l'écran en interne). Sans ce fichier correct,
 * l'écran restera noir même si le code compile sans erreur.
 * ============================================================ */

#include <Arduino.h>
#include <Wire.h>
#include <TFT_eSPI.h>
#include <Adafruit_MPU6050.h>
#include <Adafruit_Sensor.h>
#include <RTClib.h>
#include <OneWire.h>
#include <DallasTemperature.h>

// --- Broches (À ADAPTER selon les GPIO libres de votre carte) ---
#define PIN_BTN_MODE   0    // Bouton haut : changer de mode d'affichage
#define PIN_BTN_SET    14   // Bouton bas  : calibrage / réglage
#define PIN_ONEWIRE    17   // Sonde DS18B20 (température extérieure)
// SDA / SCL : utiliser les broches I2C par défaut de la carte (souvent
// GPIO 8/9 ou GPIO 21/22 selon le modèle - voir la doc du vendeur).
// Le bus I2C est PARTAGÉ entre le MPU-6050 et le DS3231.

TFT_eSPI tft = TFT_eSPI();
Adafruit_MPU6050 mpu;
RTC_DS3231 rtc;
OneWire oneWire(PIN_ONEWIRE);
DallasTemperature exteriorTemp(&oneWire);

// --- État de l'application ---
enum Mode { MODE_INCLINOMETRE, MODE_HORLOGE, MODE_VEILLE, MODE_COUNT };
Mode currentMode = MODE_HORLOGE;

float pitchOffset = 0.0f;
float rollOffset  = 0.0f;

// --- Anti-rebond non bloquant (n'utilise jamais delay() ni while()) ---
bool lastRawState = HIGH;
bool debouncedState = HIGH;
unsigned long lastEdgeTime = 0;
unsigned long pressStartTime = 0;
bool longPressHandled = false;

const unsigned long DEBOUNCE_MS   = 30;
const unsigned long LONG_PRESS_MS = 1500;
const unsigned long REFRESH_MS    = 200;    // ~5 rafraîchissements/s
unsigned long lastRefresh = 0;
unsigned long lastTempRead = 0;
float lastExteriorTempC = NAN;

void setup() {
  Serial.begin(115200);

  pinMode(PIN_BTN_MODE, INPUT_PULLUP);
  pinMode(PIN_BTN_SET, INPUT_PULLUP);

  Wire.begin();

  tft.init();
  tft.setRotation(1);
  tft.fillScreen(TFT_BLACK);
  tft.setTextColor(TFT_WHITE, TFT_BLACK);

  if (!mpu.begin()) {
    tft.drawString("Erreur MPU6050", 10, 10, 2);
  } else {
    mpu.setAccelerometerRange(MPU6050_RANGE_2_G);
    mpu.setGyroRange(MPU6050_RANGE_250_DEG);
    mpu.setFilterBandwidth(MPU6050_BANDWIDTH_21_HZ);
  }

  if (!rtc.begin()) {
    tft.drawString("Erreur RTC DS3231", 10, 30, 2);
  } else if (rtc.lostPower()) {
    // Ne se déclenche qu'une fois, à la première mise sous tension
    // (pile CR2032 neuve). Décommenter la ligne suivante puis
    // reflasher UNE FOIS pour régler l'heure sur celle de compilation :
    // rtc.adjust(DateTime(F(__DATE__), F(__TIME__)));
  }

  exteriorTemp.begin();
  delay(200); // laisse le temps aux capteurs de démarrer (une seule fois, au boot)
}

// Lit l'état du bouton avec anti-rebond ; retourne un évènement :
// 0 = rien, 1 = appui court relâché, 2 = appui long détecté (une seule fois)
int pollButton(int pin, bool &rawLast, bool &debounced, unsigned long &edgeTime,
               unsigned long &pressStart, bool &longHandled) {
  bool raw = digitalRead(pin);
  int event = 0;

  if (raw != rawLast) {
    edgeTime = millis();
    rawLast = raw;
  }

  if ((millis() - edgeTime) > DEBOUNCE_MS && raw != debounced) {
    debounced = raw;
    if (debounced == LOW) {
      pressStart = millis();
      longHandled = false;
    } else {
      unsigned long heldFor = millis() - pressStart;
      if (heldFor < LONG_PRESS_MS && !longHandled) {
        event = 1; // appui court
      }
    }
  }

  if (debounced == LOW && !longHandled && (millis() - pressStart) >= LONG_PRESS_MS) {
    longHandled = true;
    event = 2; // appui long
  }

  return event;
}

void drawInclinometre(float pitch, float roll) {
  tft.fillScreen(TFT_BLACK);
  tft.drawString("INCLINOMETRE", 10, 8, 4);
  tft.drawString("Tangage: " + String(pitch, 1) + "  ", 10, 55, 4);
  tft.drawString("Roulis : " + String(roll, 1) + "  ", 10, 90, 4);
  if (abs(pitch) > 30 || abs(roll) > 30) {
    tft.setTextColor(TFT_RED, TFT_BLACK);
    tft.drawString("ANGLE CRITIQUE", 10, 130, 2);
    tft.setTextColor(TFT_WHITE, TFT_BLACK);
  }
}

void drawHorloge(DateTime now, float tempC) {
  tft.fillScreen(TFT_BLACK);
  char buf[9];
  snprintf(buf, sizeof(buf), "%02d:%02d:%02d", now.hour(), now.minute(), now.second());
  tft.drawString(buf, 20, 40, 7);
  if (!isnan(tempC)) {
    tft.drawString("Ext: " + String(tempC, 1) + "C  ", 20, 110, 4);
  } else {
    tft.drawString("Ext: --  ", 20, 110, 4);
  }
}
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
